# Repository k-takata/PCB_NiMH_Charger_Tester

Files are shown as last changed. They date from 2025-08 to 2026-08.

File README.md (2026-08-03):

# NiMH充電器&測定器 (NiMH Charger & Tester) (Rev. 2)

## 概要

ニッケル水素電池を充電したり、内部抵抗や容量を測定します。

参考文献\[1\]や\[2\]の記事を参考に設計した回路となっています。

## 使用したソフトウェア

KiCad 9.0

## 回路図

Rev. 1
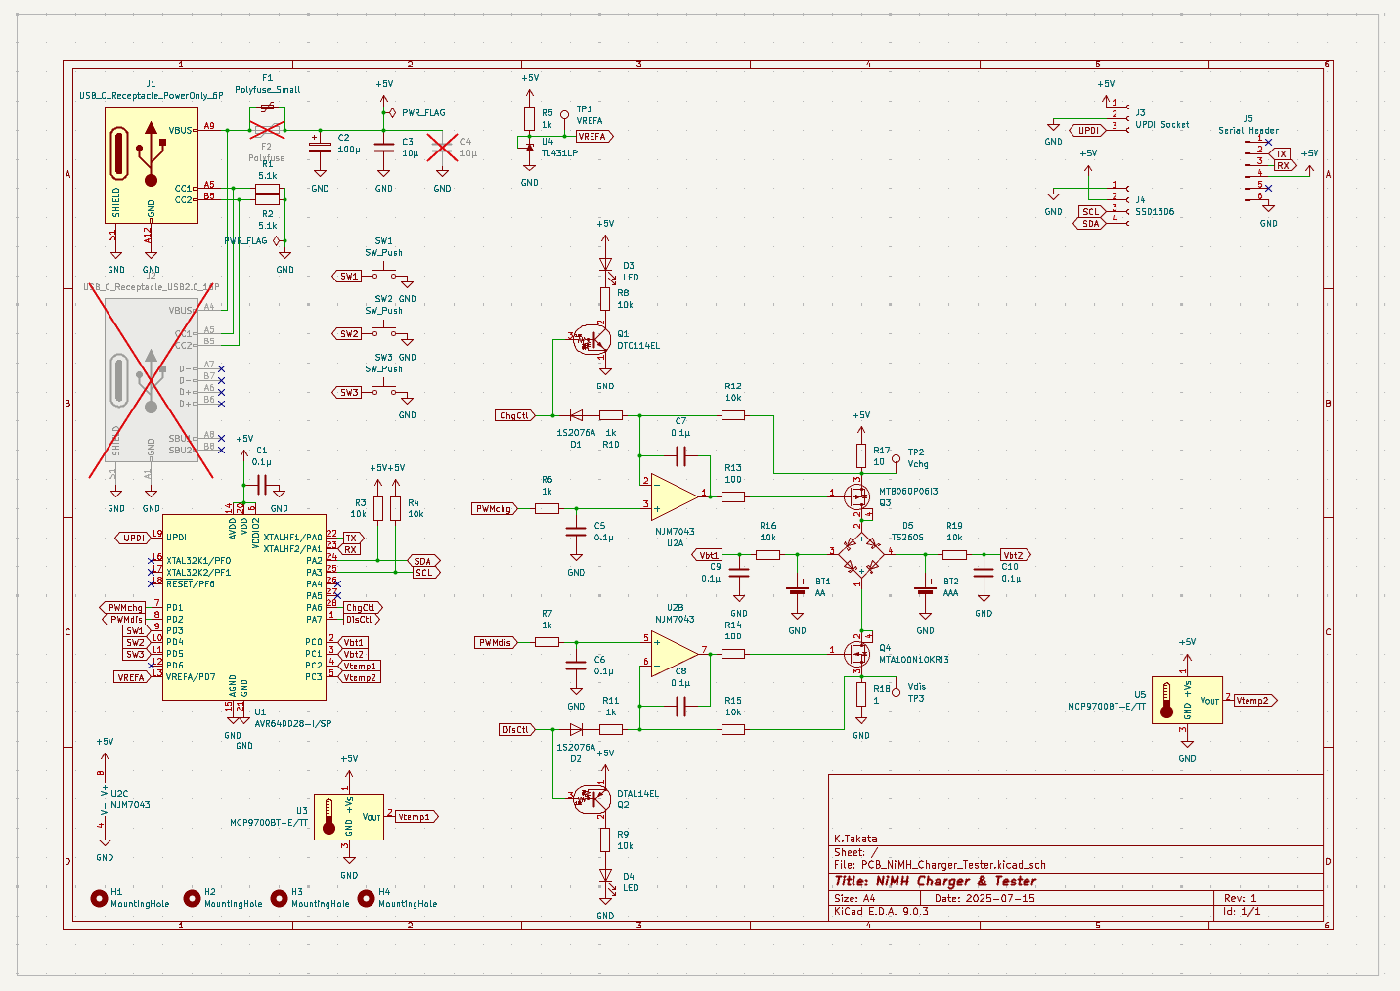
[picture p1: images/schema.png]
schema


## 基板パターン図

Rev. 1
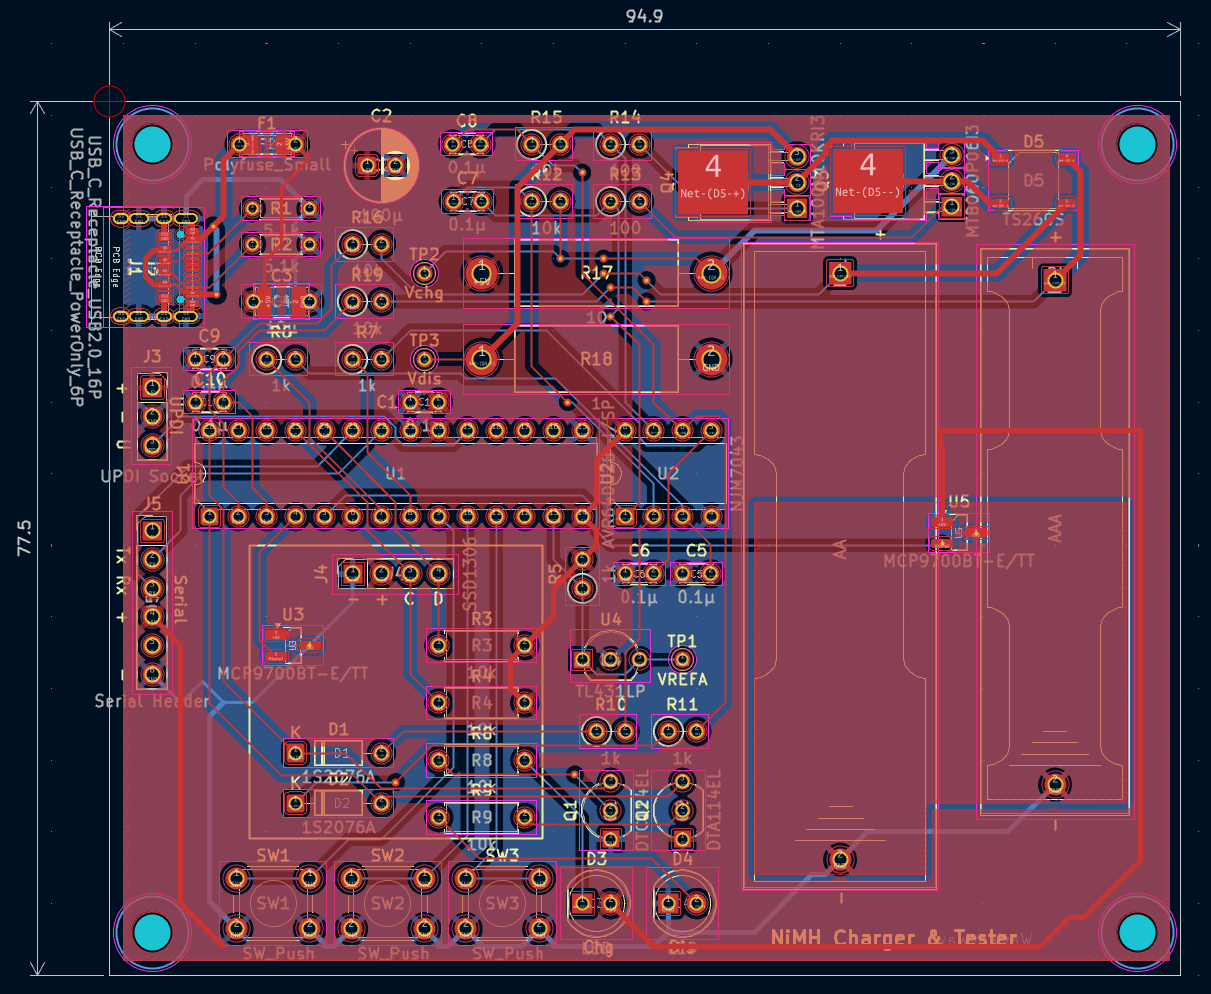
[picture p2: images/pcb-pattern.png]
PCB pattern


## 部品表

| Reference |個数|値 | 説明 |
|---|----|---|---|
|BT1 | 1| |[単3電池ボックス](https://akizukidenshi.com/catalog/g/g100308/)|
|BT2 | 1| |[単4電池ボックス](https://akizukidenshi.com/catalog/g/g102670/)|
|C1, C5, C6, C7, C8, C9, C10| 7|0.1μF|[積層セラミックコンデンサー 2.5mm](https://akizukidenshi.com/catalog/g/g113582/)|
|C2 | 1|100μF|電解コンデンサー φ6.3|
|C3 (\*1) | 1| 10μF|積層セラミックコンデンサー 3225M|
|C4 (\*1) | 1| 10μF|[積層セラミックコンデンサー 5mm](https://akizukidenshi.com/catalog/g/g103095/)|
|D1, D2 | 2|1S2076A|小信号用汎用ダイオード|
|D3 | 1|[OS5REA51A5A](https://akizukidenshi.com/catalog/g/g114209/)|赤色LED (ミルキーレンズ)、充電表示LED|
|D4 | 1|[OSG5DA51A5A](https://akizukidenshi.com/catalog/g/g114207/)|緑色LED (ミルキーレンズ)、放電表示LED|
|D5 (\*2) | 1|[TS260S](https://akizukidenshi.com/catalog/g/g115166/)|表面実装用ショットキーバリアダイオードブリッジ 60V 2A|
|~~D6~~ (\*2) | ~~1~~|~~S1ZB20~~|~~ダイオードブリッジ 200V 0.8A~~|
|F1 (\*3) | 1|  0.5A|[ポリヒューズ](https://akizukidenshi.com/catalog/g/g115300/)、表面実装|
|F2 (\*3) | 1|  1.1A|[ポリヒューズ](https://akizukidenshi.com/catalog/g/g100507/)|
|J1 (\*4) | 1| |[USB Type-Cコネクター 電源供給用](https://akizukidenshi.com/catalog/g/g116438/)|
|J2 (\*4) | 1| |[USB Type-Cコネクター](https://akizukidenshi.com/catalog/g/g114356/)|
|J3 (\*5) | 1| |ピンヘッダー 1x4、UPDI用|
|J4 | 1| |[ロープロファイルピンソケット](https://akizukidenshi.com/catalog/g/g100661/) 1x4、OLED接続用|
|J5 | 1| |ピンヘッダー 1x6、シリアル通信用|
|Q1 | 1|[DTC114EL](https://akizukidenshi.com/catalog/g/g112467/)|抵抗入りNPNトランジスター|
|Q2 | 1|[DTA114EL](https://akizukidenshi.com/catalog/g/g112464/)|抵抗入りPNPトランジスター|
|Q3 | 1|[MTB060P06I3](https://akizukidenshi.com/catalog/g/g116095/)|PchパワーMOSFET 60V 16.7A|
|Q4 | 1|[MTA100N10KRI3](https://akizukidenshi.com/catalog/g/g115847/)|NchパワーMOSFET 100V 10A|
|R1, R2 | 2|5.1kΩ|緑茶赤金、1/6Wサイズ|
|R3, R4, R12, R15, R16, R19 | 6| 10kΩ|茶黒橙金、1/4Wサイズ|
|R5, R6, R7, R10, R11 | 5|  1kΩ|茶黒赤金、1/4Wサイズ|
|R8 (\*6) | 1| 22kΩ|赤赤橙金、1/4Wサイズ、充電表示LED電流制限用 (4.7kΩ～47kΩ)|
|R9 (\*6) | 1| 47kΩ|黄紫橙金、1/4Wサイズ、放電表示LED電流制限用 (4.7kΩ～47kΩ)|
|R13, R14 | 2| 100Ω|茶黒茶金、1/4Wサイズ|
|R17 | 1|  10Ω|茶黒黒金茶、[酸化金属皮膜抵抗 3W 10Ω](https://akizukidenshi.com/catalog/g/g111015/)|
|R18 | 1| 1Ω|茶黒黒銀茶、[酸化金属皮膜抵抗 3W 1Ω](https://akizukidenshi.com/catalog/g/g111013/)|
|SW1 | 1|[DTS-63-N-V-RED](https://akizukidenshi.com/catalog/g/g103646/)|タクトスイッチ (赤色)|
|SW2 | 1|[DTS-63-N-V-GRN](https://akizukidenshi.com/catalog/g/g103651/)|タクトスイッチ (緑色)|
|SW3 | 1|[DTS-63-N-V-BLU](https://akizukidenshi.com/catalog/g/g103649/)|タクトスイッチ (水色)|
|U1 | 1|[AVR64DD28-I/SP](https://akizukidenshi.com/catalog/g/g118314/)|AVRマイコン|
|U2 | 1|[NJU7043](https://akizukidenshi.com/catalog/g/g106840/)|2回路入入出力フルスイングオペアンプ|
|U3, U5 | 1|[MCP9700BT-E/TT](https://akizukidenshi.com/catalog/g/g130948/)|温度センサーIC|
|U4 | 1|[TL431](https://akizukidenshi.com/catalog/g/g112018/)|シャントレギュレーター 2.495V|

注:
* (\*1) C3, C4はどちらかを選択します。基板上にはC3の表示のみあります。
* (\*2) ~~(Rev. 2から) D5, D6はどちらかを選択します。基板上にはD6の表示のみあります。~~ D6はピンピッチが間違っていたため取り付け不可。
* (\*3) F1, F2はどちらかを選択します。基板上にはF1の表示のみあります。
* (\*4) J1, J2は部品の入手状況や実装難易度を考慮してどちらかを選択します。J1を選択した場合は、基板から少しはみ出す状態で取り付けることになります。J2を選択した場合は、J1用のランドとコネクター本体がショートしないようにポリイミドテープ等で絶縁する必要があります。
* (\*5) Rev. 1ではピンソケット 1x3でしたが、Rev. 2ではピンヘッダー 1x4に変更されています。
* (\*6) LEDの明るさを変えたい場合は適宜値を変更します。ここでは暗めに設定しています。

## 作成

[NiMH充電器&測定器の作成 (その1、ハードウェア編)](https://zenn.dev/k_takata/articles/nimh-charger-tester-1)を参照してください。

## 使用方法

[NiMH充電器&測定器の作成 (その2、ソフトウェア編)](https://zenn.dev/k_takata/articles/nimh-charger-tester-2)を参照してください。

## 変更差分

Rev. 2での変更点は以下の通りです。

* 充放電電流を測定できるようにTP2 (Vchg)とPF0ピンを接続し、TP3 (Vdis)とPF1ピンを接続。
* ICを取り外しやすくなるようにAVRマイコンの位置を調整。
* UPDIコネクターを[AVR Programming Adapter](https://www.microchip.com/en-us/development-tool/AC31S18A)に合わせて、4pinのピンヘッダーに変更。向きも反転。
* OLEDのコネクターの位置を調整。
* ピンヘッダーやピンソケットのぐらつきが少なくなるようにドリル径を調整。
* 単3電池の "+" マークのシルクの位置がずれていたのを修正。
* ブリッジダイオードをD5とD6で選択可能にした。
* TTLシリアル端子のピン順序(シルク)が逆になっていたのを修正。

## 完成品

充電完了後にグラフを表示している様子 (Rev. 1):
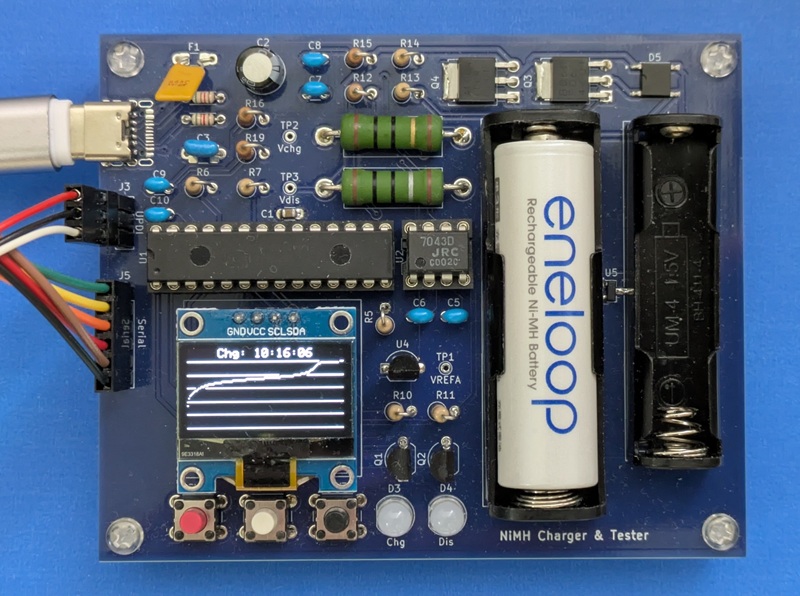
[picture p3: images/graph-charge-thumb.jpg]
完成品


## 参考文献

1. [トランジスタ技術SPECIAL No.135 Liイオン/鉛/NiMH蓄電池の充電&電源技術](https://shop.cqpub.co.jp/hanbai/books/46/46751.html)<br/>
   「第4章　研究！ ニッケル水素蓄電池の耐久テスト」 下間 憲行著
2. [トランジスタ技術SPECIAL No.170 教科書付き 小型バッテリ電源回路](https://www.cqpub.co.jp/trs/trsp170.htm)<br/>
   「Appendix 1　充放電回数の限界…サイクル耐久特性の実測」 下間 憲行著
3. [電池応用ハンドブック](https://www.cqpub.co.jp/hanbai/books/34/34461.htm)

## License

CC0

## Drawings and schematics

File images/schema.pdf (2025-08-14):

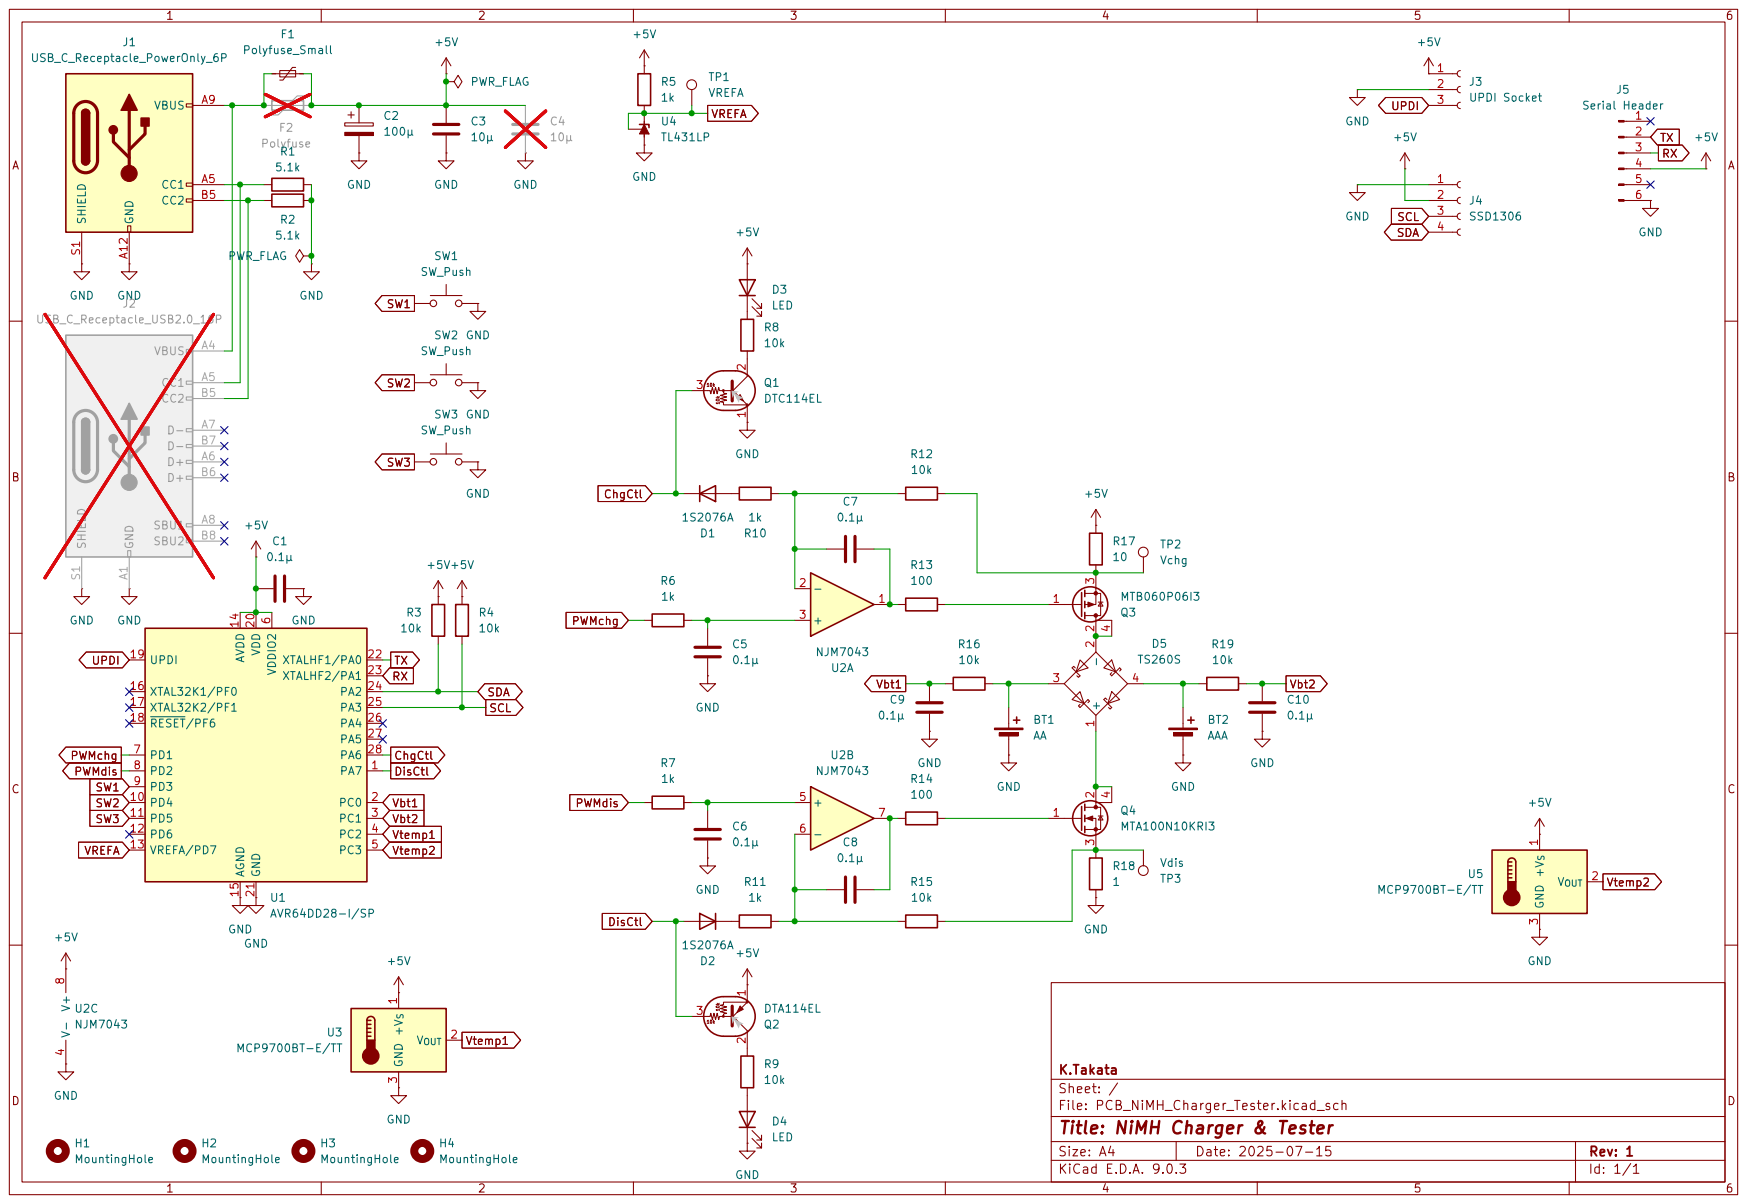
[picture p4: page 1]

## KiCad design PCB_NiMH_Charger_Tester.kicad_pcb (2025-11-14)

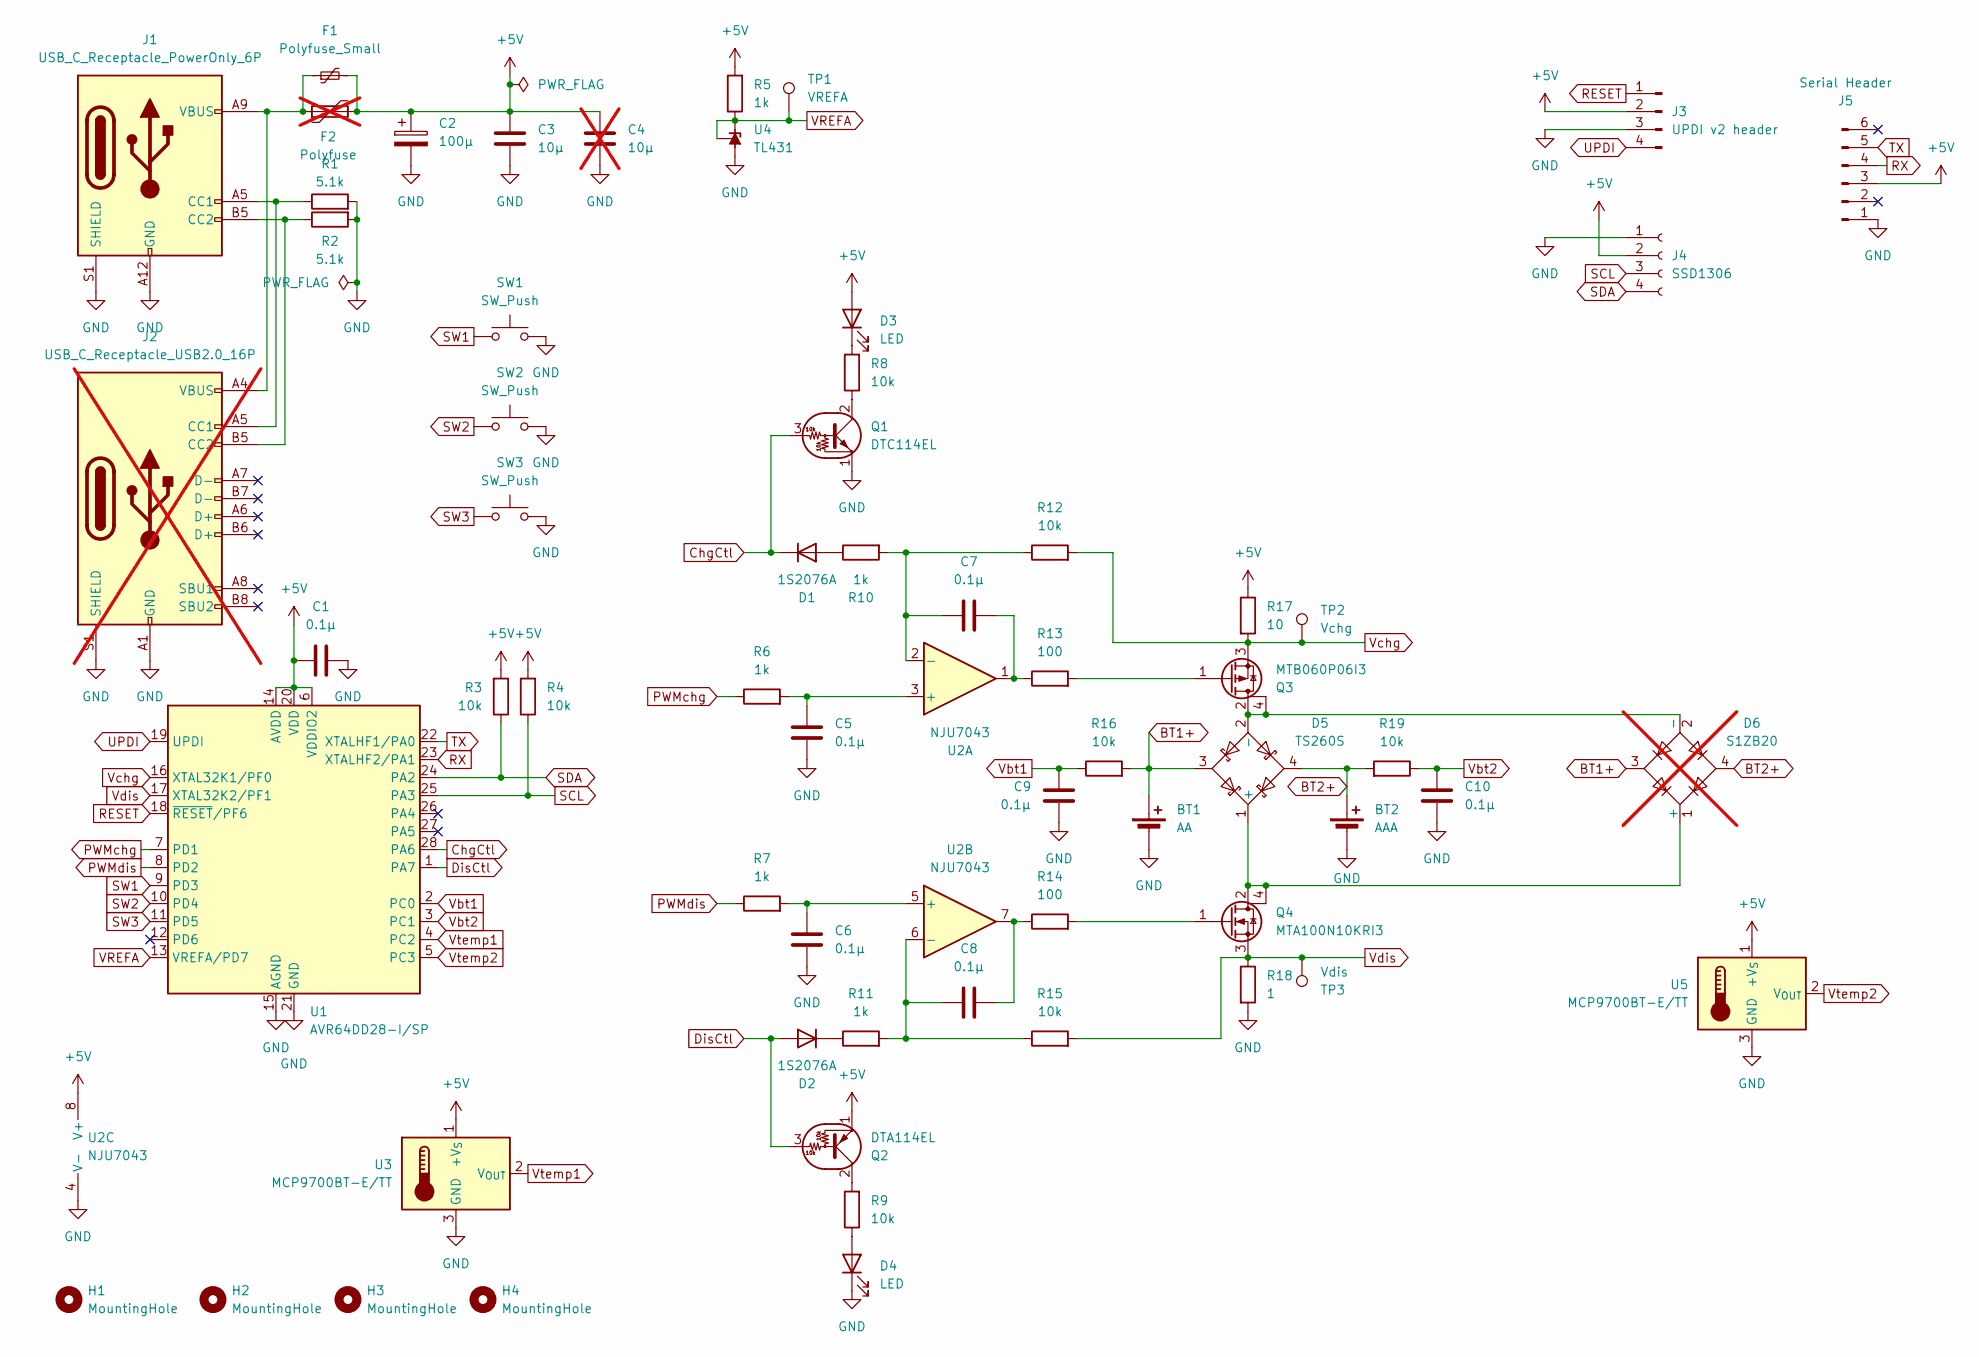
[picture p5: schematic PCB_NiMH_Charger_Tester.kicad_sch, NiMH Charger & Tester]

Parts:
BT1: AA; BatteryHolder_Keystone_2460_1xAA
BT2: AAA; BatteryHolder_Keystone_2466_1xAAA
C1, C5, C6, C7, C8, C9, C10: 0.1μ; C_Disc_D3.0mm_W1.6mm_P2.50mm
C2: 100μ; CP_Radial_D6.3mm_P2.50mm
C3: 10μ; C_1210_3225Metric_Pad1.33x2.70mm_HandSolder
C4: 10μ; C_Disc_D4.7mm_W2.5mm_P5.00mm; not fitted
D1, D2: 1S2076A; D_DO-35_SOD27_P7.62mm_Horizontal
D3: LED; LED_D5.0mm
D4: LED; LED_D5.0mm_Clear
D5: TS260S; TSSOP-4_4.4x5mm_P4mm
D6: S1ZB20; Diode_Bridge_DIP-4_W5.08mm_P2.54mm; not fitted
F1: Polyfuse_Small; Fuse_1206_3216Metric_Pad1.42x1.75mm_HandSolder
F2: Polyfuse; C_Disc_D4.3mm_W1.9mm_P5.00mm; not fitted
H1, H2, H3, H4: MountingHole; MountingHole_3.2mm_M3
J1: USB_C_Receptacle_PowerOnly_6P; USB_C_Receptacle_GCT_USB4125-xx-x_6P_TopMnt_Horizontal
J2: USB_C_Receptacle_USB2.0_16P; USB_C_Receptacle_GCT_USB4105-xx-A_16P_TopMnt_Horizontal; not fitted
J3: UPDI v2 header; PinHeader_1x04_P2.54mm_Vertical
J4: SSD1306; PinSocket_1x04_P2.54mm_Vertical
J5: Serial Header; PinHeader_1x06_P2.54mm_Vertical
Q1: DTC114EL; TO-92_Inline_Wide
Q2: DTA114EL; TO-92_Inline_Wide
Q3: MTB060P06I3; TO-251-3-1EP_Horizontal_TabDown
Q4: MTA100N10KRI3; TO-251-3-1EP_Horizontal_TabDown
R1, R2: 5.1k; R_Axial_DIN0204_L3.6mm_D1.6mm_P5.08mm_Horizontal
R3, R4, R8, R9: 10k; R_Axial_DIN0207_L6.3mm_D2.5mm_P7.62mm_Horizontal
R5, R6, R7, R10, R11: 1k; R_Axial_DIN0207_L6.3mm_D2.5mm_P2.54mm_Vertical
R12, R15, R16, R19: 10k; R_Axial_DIN0207_L6.3mm_D2.5mm_P2.54mm_Vertical
R13, R14: 100; R_Axial_DIN0207_L6.3mm_D2.5mm_P2.54mm_Vertical
R17: 10; R_Axial_DIN0614_L14.3mm_D5.7mm_P20.32mm_Horizontal
R18: 1; R_Axial_DIN0614_L14.3mm_D5.7mm_P20.32mm_Horizontal
SW1, SW2, SW3: SW_Push; SW_PUSH_6mm
TP1: VREFA; TestPoint_THTPad_D1.5mm_Drill0.7mm
TP2: Vchg; TestPoint_THTPad_D1.5mm_Drill0.7mm
TP3: Vdis; TestPoint_THTPad_D1.5mm_Drill0.7mm
U1: AVR64DD28-I/SP; DIP-28_W7.62mm
U2: NJU7043; DIP-8_W7.62mm
U3, U5: MCP9700BT-E/TT; SOT-23_Handsoldering
U4: TL431; TO-92_Inline_Wide

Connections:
+5V: C1.2, C2.1, C3.1, C4.1, D3.2 (A), F1.2, F2.2, J3.2, J4.2, J5.3, Q2.1 (G), R3.2, R4.2, R5.2, R17.1, U1.6 (VDDIO2), U1.14 (AVDD), U1.20 (VDD), U2.8 (V+), U3.1 (+V_{S}), U5.1 (+V_{S})
BT1+: BT1.1 (+), D5.3, D6.3, R16.2
BT2+: BT2.1 (+), D5.4, D6.4, R19.2
ChgCtl: D1.1 (K), Q1.3 (I), U1.28 (PA6)
DisCtl: D2.2 (A), Q2.3 (I), U1.1 (PA7)
GND: BT1.2 (-), BT2.2 (-), C1.1, C2.2, C3.2, C4.2, C5.1, C6.1, C9.1, C10.1, D4.1 (K), J1.A12 (GND), J1.B12 (GND), J1.S1 (SHIELD), J2.A1 (GND), J2.A12 (GND), J2.B1 (GND), J2.B12 (GND), J2.S1 (SHIELD), J3.3, J4.1, J5.1, Q1.1 (G), R1.2, R2.2, R18.2, SW1.2, SW2.2, SW3.2, U1.15 (AGND), U1.21 (GND), U2.4 (V-), U3.3 (GND), U4.2 (A), U5.3 (GND)
unnamed: C7.2, R13.1, U2.1
unnamed: C8.2, R14.1, U2.7
unnamed: D1.2 (A), R10.1
unnamed: D2.1 (K), R11.1
unnamed: D3.1 (K), R8.2
unnamed: D4.2 (A), R9.1
unnamed: D5.1 (+), D6.1 (+), Q4.2 (D), Q4.4 (D)
unnamed: D5.2 (-), D6.2 (-), Q3.2 (D), Q3.4 (D)
unnamed: F1.1, F2.1, J1.A9 (VBUS), J1.B9 (VBUS), J2.A4 (VBUS), J2.A9 (VBUS), J2.B4 (VBUS), J2.B9 (VBUS)
unnamed: J1.A5 (CC1), J2.A5 (CC1), R1.1
unnamed: J1.B5 (CC2), J2.B5 (CC2), R2.1
unnamed: Q1.2 (O), R8.1
unnamed: Q2.2 (O), R9.2
unnamed: Q3.1 (G), R13.2
unnamed: Q4.1 (G), R14.2
unnamed: C5.2, R6.2, U2.3 (+)
unnamed: C7.1, R10.2, R12.1, U2.2 (-)
unnamed: C6.2, R7.2, U2.5 (+)
unnamed: C8.1, R11.2, R15.1, U2.6 (-)
PWMchg: R6.1, U1.7 (PD1)
PWMdis: R7.1, U1.8 (PD2)
RESET: J3.1, U1.18 (~RESET/PF6)
RX: J5.4, U1.23 (XTALHF2/PA1)
SCL: J4.3, R4.1, U1.25 (PA3)
SDA: J4.4, R3.1, U1.24 (PA2)
SW1: SW1.1, U1.9 (PD3)
SW2: SW2.1, U1.10 (PD4)
SW3: SW3.1, U1.11 (PD5)
TX: J5.5, U1.22 (XTALHF1/PA0)
UPDI: J3.4, U1.19 (UPDI)
VREFA: R5.1, TP1.1, U1.13 (VREFA/PD7), U4.1 (REF), U4.3 (K)
Vbt1: C9.2, R16.1, U1.2 (PC0)
Vbt2: C10.2, R19.1, U1.3 (PC1)
Vchg: Q3.3 (S), R12.2, R17.2, TP2.1, U1.16 (XTAL32K1/PF0)
Vdis: Q4.3 (S), R15.2, R18.1, TP3.1, U1.17 (XTAL32K2/PF1)
Vtemp1: U1.4 (PC2), U3.2 (V_{OUT})
Vtemp2: U1.5 (PC3), U5.2 (V_{OUT})

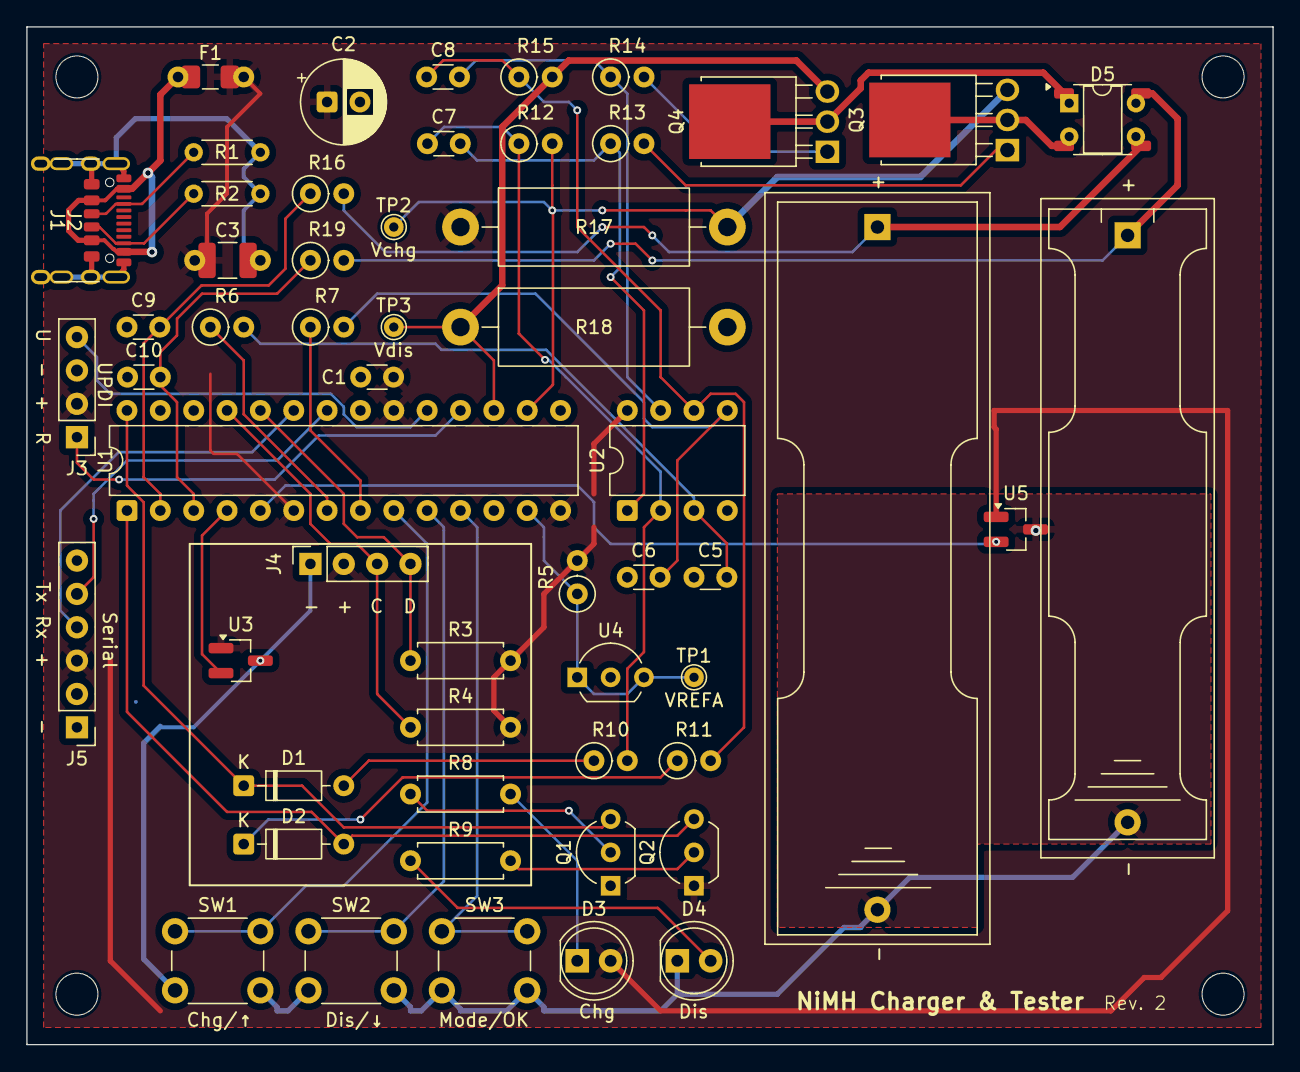
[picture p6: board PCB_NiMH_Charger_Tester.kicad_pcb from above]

Board: 2 copper layers, 94.9 x 77.5 mm, 63 parts (0 on the bottom side), 43 nets.

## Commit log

2025-08-12 Initial implementation
    [PCB_NiMH_Charger_Tester.kicad_pcb, PCB_NiMH_Charger_Tester.kicad_sch]
2025-08-13 Add title
    [PCB_NiMH_Charger_Tester.kicad_pcb]
2025-08-14 Fix parts name
    [PCB_NiMH_Charger_Tester.kicad_sch]
2025-08-18 シルクの位置を調整
    BT1の "+" の位置がずれていたのを修正。
    [PCB_NiMH_Charger_Tester.kicad_pcb]
2025-08-24 Update
    * Adjust the position of SS1306.
    * Support S1ZB20.
    [PCB_NiMH_Charger_Tester.kicad_pcb, PCB_NiMH_Charger_Tester.kicad_sch]
2025-08-24 Rev. 2
    [PCB_NiMH_Charger_Tester.kicad_pcb, PCB_NiMH_Charger_Tester.kicad_sch]
2025-08-30 Adjust OLED hole size
    [PCB_NiMH_Charger_Tester.kicad_pcb]
2025-08-31 Adjust drill size
    [PCB_NiMH_Charger_Tester.kicad_pcb]
2025-08-31 Adjust U1 position
    [PCB_NiMH_Charger_Tester.kicad_pcb]
2025-08-31 Update UPDI connector
    Use the official UPDI v2 connector.
    See "AVR Programming Adapter":
    https://www.microchip.com/en-us/development-tool/AC31S18A
    [PCB_NiMH_Charger_Tester.kicad_pcb, PCB_NiMH_Charger_Tester.kicad_sch]
2025-08-31 W/A for DRC errors
    * Adjust +5V zones. Explicitly connect two zones.
    * Adjust D5 silkscreen.
    [PCB_NiMH_Charger_Tester.kicad_pcb]
2025-08-31 Adjust J3,J5 position
    [PCB_NiMH_Charger_Tester.kicad_pcb]
2025-09-04 Adjust resistor values
    [PCB_NiMH_Charger_Tester.kicad_pcb, PCB_NiMH_Charger_Tester.kicad_sch]
2025-09-04 Replace S1ZB20 symbol
    It is not a Schottky Bridge, PN Bridge.
    [PCB_NiMH_Charger_Tester.kicad_pcb, PCB_NiMH_Charger_Tester.kicad_sch]
2025-09-05 Reverse Serial Header
    [PCB_NiMH_Charger_Tester.kicad_pcb, PCB_NiMH_Charger_Tester.kicad_sch]
2025-09-11 Change drill size
    J3, J5: Normal pin header: 0.9mm -> 0.8mm
    J4: Pin socket: 0.9mm -> 0.8mm
    [PCB_NiMH_Charger_Tester.kicad_pcb]
2025-09-19 Update silk
    [PCB_NiMH_Charger_Tester.kicad_pcb]
2025-09-25 Connect Vchg/Vdis to AVR
    Also, change J3/J5 direction.
    [PCB_NiMH_Charger_Tester.kicad_pcb, PCB_NiMH_Charger_Tester.kicad_sch]
2025-09-30 Update button name
    [PCB_NiMH_Charger_Tester.kicad_pcb]
2025-10-15 Revert resistor values
    [PCB_NiMH_Charger_Tester.kicad_pcb, PCB_NiMH_Charger_Tester.kicad_sch]
2025-10-15 Update README
    Change the color of the switches.
2025-10-17 Change resistor values
2025-10-18 Stop using D6
    Footprint was wrong.
2025-11-14 Fix D6 footprint
    [PCB_NiMH_Charger_Tester.kicad_pcb, PCB_NiMH_Charger_Tester.kicad_sch]
2026-08-03 Fix typo in UPDI connector description in README
